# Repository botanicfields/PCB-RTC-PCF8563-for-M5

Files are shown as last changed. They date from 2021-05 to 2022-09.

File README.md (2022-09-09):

## PCB-RTC-PCF8563-for-M5
a PCB of PCF8563-RTC with Grove-I2C for M5Stack and M5Atom synchronized with NTP

# M5 用リアルタイムクロック (RTC) 基板
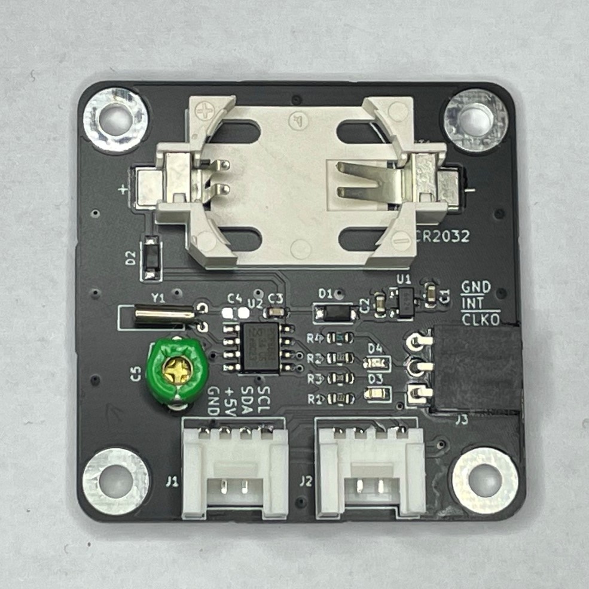
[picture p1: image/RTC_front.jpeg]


　M5 シリーズ用に作成した RTC 基板です。水晶振動子 により高精度に時刻を刻みます。バッテリ・バックアップにより本体が電源オフの状態でも時刻を維持します。

- M5 仕様の Grove コネクタ

    　M5 製品の Grove コネクタ仕様（電源 5V, 信号レベル 3.3V）に合致します。Grove コネクタが 2 個あり、I2C デバイスの数珠つなぎができます。

- M5 製品と同仕様の RTC

    　M5Core2, M5StickC/C Plus, M5CoreInk, M5Paper, M5Camera/F/X に内蔵されている BM8563 と互換の RTC(PCF8563) を搭載し、M5 用の多くのソフトウェアを利用できます。

- INT, CLKO 信号出力

    　PCF8563(BM8563) の INT 信号、CLKO 信号を、基板上のピンソケットから取り出せます。これらの信号は 3.3V に 10kΩ でプルアップしています。基板上の LED（INT: 赤、CLKO： 緑）で信号オンを確認できます。

- 時刻の精度を改善

    　基板上にトリマコンデンサを搭載し、時刻の精度を改善できます。出荷時には、以下の機器を用いて室温（15 - 25 ℃程度のどこか）にて調整済です。（※固定コンデンサ C4, トリマコンデンサ C5 はどちらか一方を実装します。トリマコンデンサを実装している場合、C4 には部品がありません。）

>> 1. 周波数カウンタ (1) を GPS 受信機 (2) の 1PPS 信号で校正
>>>> (1) 秋月電子通商「８桁周波数カウンターキット」 [AE-FCOUNT3](
https://akizukidenshi.com/catalog/g/gK-13432/)
>>>>
>>>> (2) 秋月電子通商「ＧＰＳ受信機キット～」 [AE-GYSFDMAXB](
https://akizukidenshi.com/catalog/g/gK-09991/)
>> 2. RTC 基板の CLKO から 1Hz 信号を取り出し、1PPS の代わりに入力
>> 3. 周波数カウンタの表示が所定の値に近づく様、RTC 基板上のトリマを調整

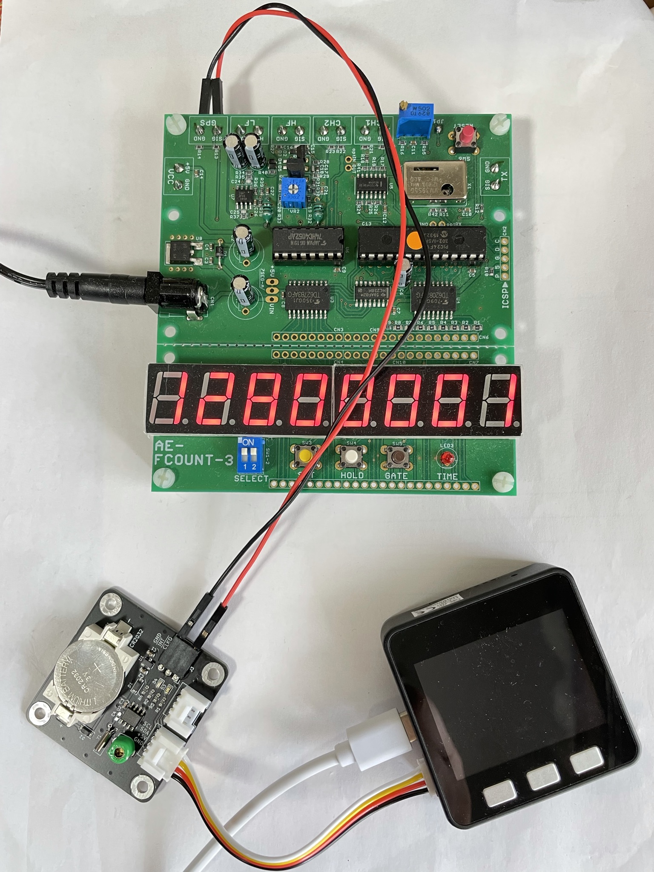
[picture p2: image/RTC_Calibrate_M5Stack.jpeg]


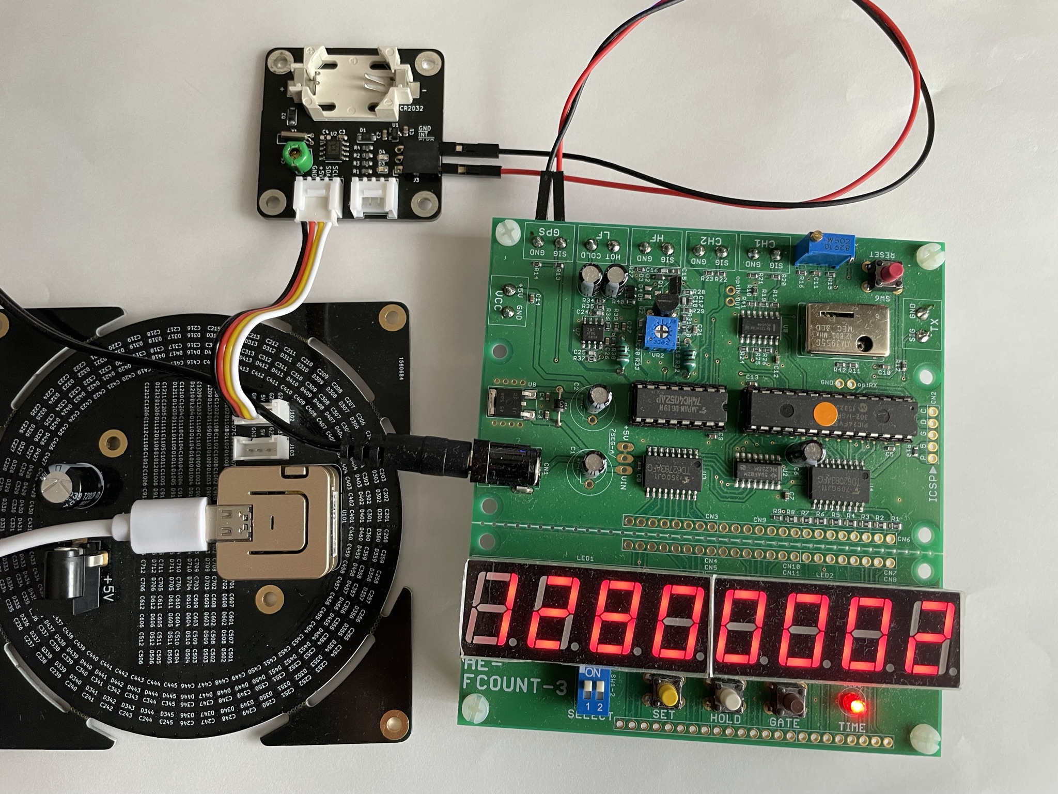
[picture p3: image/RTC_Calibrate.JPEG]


# ソフトウェア
　RTC の使用にあたっては、一般に入手可能なライブラリを利用することができます。

　他の I2C デバイスとの共存や、NTP との相互補完を想定したサンプルプログラムを作成し、BF-027 フォルダに置きました。詳細な説明は Qiita（参考を参照）にあります。これらのプログラムは M5Stack 社の [RTC ユニット](https://docs.m5stack.com/en/unit/rtc)でも使用できます。

1. BF_Pcf8563.h, BF_Pcf8563.cpp

    RTC PCF8563(BM8563) にアクセスし、時刻、アラーム、タイマー、クロック出力などの機能を使用するためのドライバです。

2. BF_Pcf8563Test.h, BF_Pcf8563Test.cpp

    上記 BF_Pcf8563.cpp の機能をテストするプログラムです。

3. BF_RtcxNtp.h, BF_RtcxNtp.cpp

    RTC と NTP を相互補完的に使用するためのプログラムです。

4. BF-027.ino

    上記プログラムの使用例です。  
- M5Stack または M5Atom で動作します。冒頭の #define で使用する方を残してコメントアウトしてください。  
- M5Atomでは RTC の接続先を GROVE コネクタか、またはピンソケットのどちらかを選べます。setup() の rtcx.Begin(Wire1) または rtcx.Begin(Wire) の使用するほうを残してコメントアウトしてください。

# 参考

(1) Qiita [「M5Atom, M5Stack Core 用の I2C リアルタイムクロック基板を作って動かす」](https://qiita.com/BotanicFields/items/dc35e12423be8f6e9b4e)

(2) Qiita [「ESP32 において NTP の時刻同期を捕まえて RTC を更新する」](https://qiita.com/BotanicFields/items/f1e28af5a63e4ccf7023)

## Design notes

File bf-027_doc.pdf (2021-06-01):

BF-027 V02

Copyright 2021 BotanicFields, Inc. 1

## M5 用リアルタイムクロック (RTC) 基板

M5 シリーズ用に作成した RTC 基板です。水晶振動子の精度で時刻を刻みます。バックアップ電池により M5 本体が電源オフの状態でも時刻を維持します。

1. 内容物（各１）
(1) プリント基板
(2) GROVE 互換ケーブル 10cm
(3) 説明書（本書）
※電池 (CR2032) は付属しません。
2. 使用方法
(1) バックアップ電池を装着すると、電源オフでも時刻を維持します
(2) GROVE コネクタ 2 個は、どちらも同じです。バス接続に利用できます
(3) GROVE コネクタは M5 シリーズの仕様に合わせ、電源は 5V, 信号 (I2C) は 3.3V です。
(4) RTC 基板上に I2C のプルアップはありません。コントローラ側などでプルアップが必要です
(5) I2C アドレスは 0x51 固定です。PCF8563/BM8563 用のソフトウェアには設定済と思います。I2C 初 期化時の SCL, SDA 設定と、M5 本体から I2C バスを取り出す GPIO 番号を合わせてください
3. ご注意
(1) 基板むき出しであり、配線に触ると誤動作します。たとえバックアップ電池を装備していても、コネクタ の抜き差し時に誤動作して時刻を喪失することもあります。
(2) トリマコンデンサは可能なかぎり調整済ですが、精度の保証はいたしません
(3) 電池 CR2032 の短絡や寿命（ 5 年）にご注意ください
(4) 本製品の誤動作やご利用上のトラブル等への補償はいたしません
4. 参考情報
(1) GitHub 「botanicfields/PCB-RTC-PCF8563-for-M5」 https://github.com/botanicfields/PCB-RTC-PCF8563-for-M5
(2) Qiita 「M5Atom, M5Stack Core 用の I2C リアルタイムクロック基板を作って動かす」 https://qiita.com/BotanicFields/items/dc35e12423be8f6e9b4e
(3) Qiita 「ESP32 において NTP の時刻同期を捕まえて RTC を更新する」 https://qiita.com/BotanicFields/items/f1e28af5a63e4ccf7023
5. 提供元
ボタニック (BotanicFields)
https://www.facebook.com/botanicfieldshttps://twitter.com/botanicfields
以上

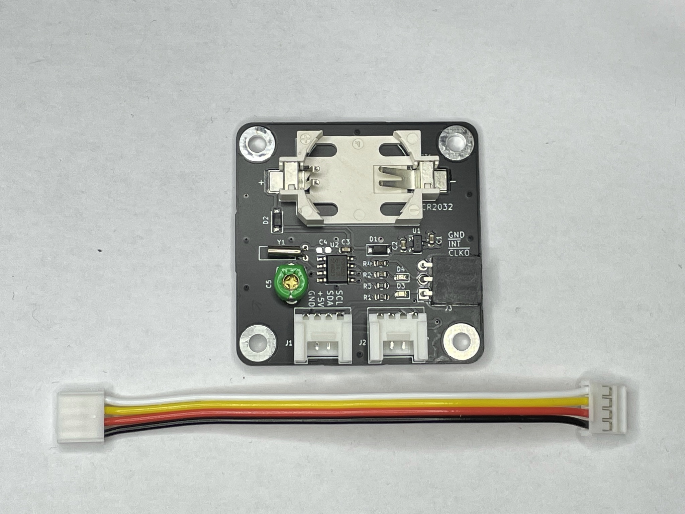
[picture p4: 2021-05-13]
image/RTC_kit.JPEG

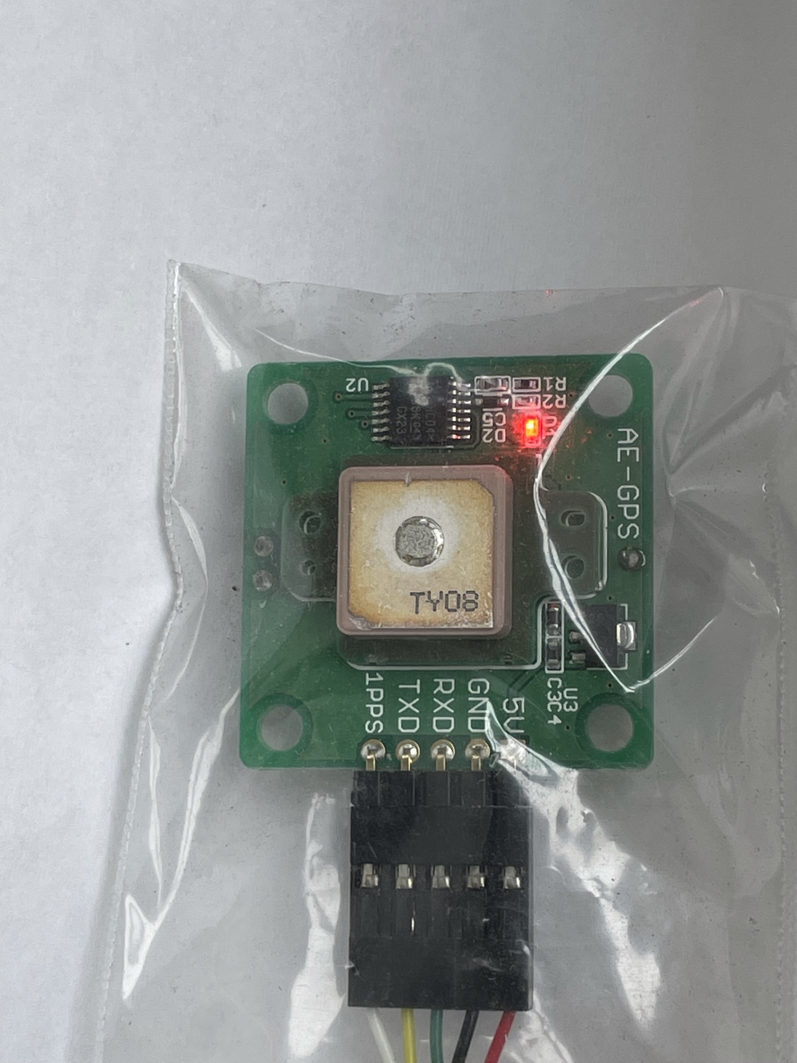
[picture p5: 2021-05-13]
image/GPS.JPEG

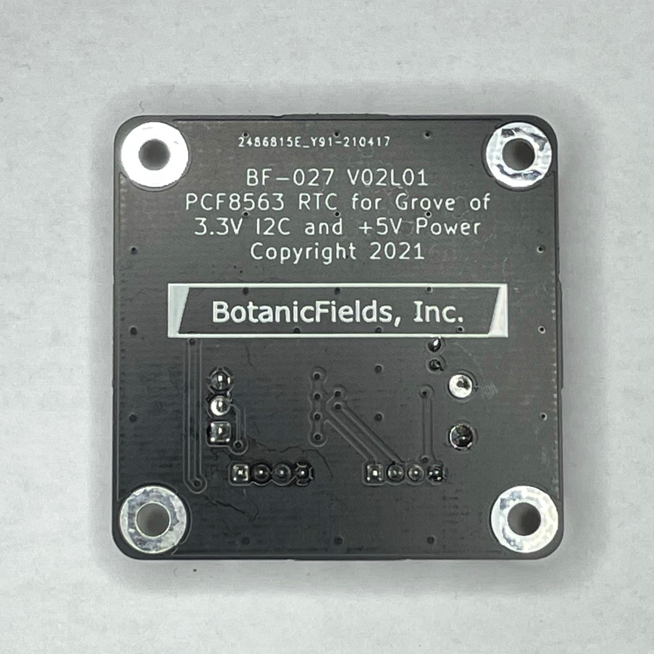
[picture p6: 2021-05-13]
image/RTC_back.jpeg

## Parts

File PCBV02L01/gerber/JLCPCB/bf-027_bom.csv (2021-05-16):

Comment | Designator | Footprint | LCSC
CR2032 | BT1 | bf:BF@QJ-BS-6 | C70377
1u | C1,C2 | Capacitor_SMD:C_0603_1608Metric | C15849
100n | C3 | Capacitor_SMD:C_0603_1608Metric | C14663
15p | C4 | Capacitor_SMD:C_0603_1608Metric | C1644
30p | C5 | bf:BF@TZ03-F
1N4148 | D1,D2 | Diode_SMD:D_SOD-123 | C81598
GREEN | D3 | LED_SMD:LED_0603_1608Metric | C72043
RED | D4 | LED_SMD:LED_0603_1608Metric | C2286
I2C | J1,J2 | opl:HW4-2.0-90D
OUT | J3 | bf:BF@PinSocket_1x03_P2.54mm_Horizontal | C225511
2.2k | R1,R2 | Resistor_SMD:R_0603_1608Metric | C4190
10k | R3,R4 | Resistor_SMD:R_0603_1608Metric | C25804
XC6206P332MR | U1 | Package_TO_SOT_SMD:SOT-23 | C5446
PCF8563T | U2 | Package_SO:SOIC-8_3.9x4.9mm_P1.27mm | C7440
32768Hz | Y1 | bf:BF@Crystal_DS26_D2.0mm_L6.0mm_Horizontal | C398714

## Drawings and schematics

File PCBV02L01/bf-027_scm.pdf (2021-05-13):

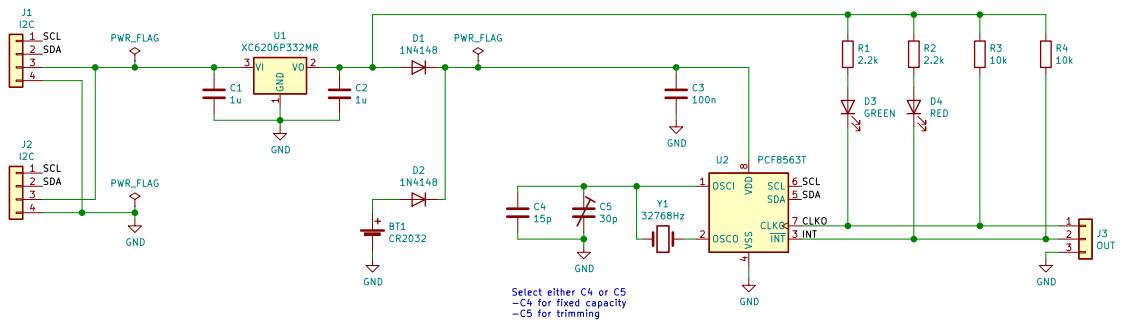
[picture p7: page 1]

File: bf-027.sch Sheet: / Copyright 2021 BotanicFields, Inc. PCF8563 RTC for Grove of 3.3V I2C 5V Power D3 GREEN GND

4 SDA 5 SCL 6 CLKO 7 VDD

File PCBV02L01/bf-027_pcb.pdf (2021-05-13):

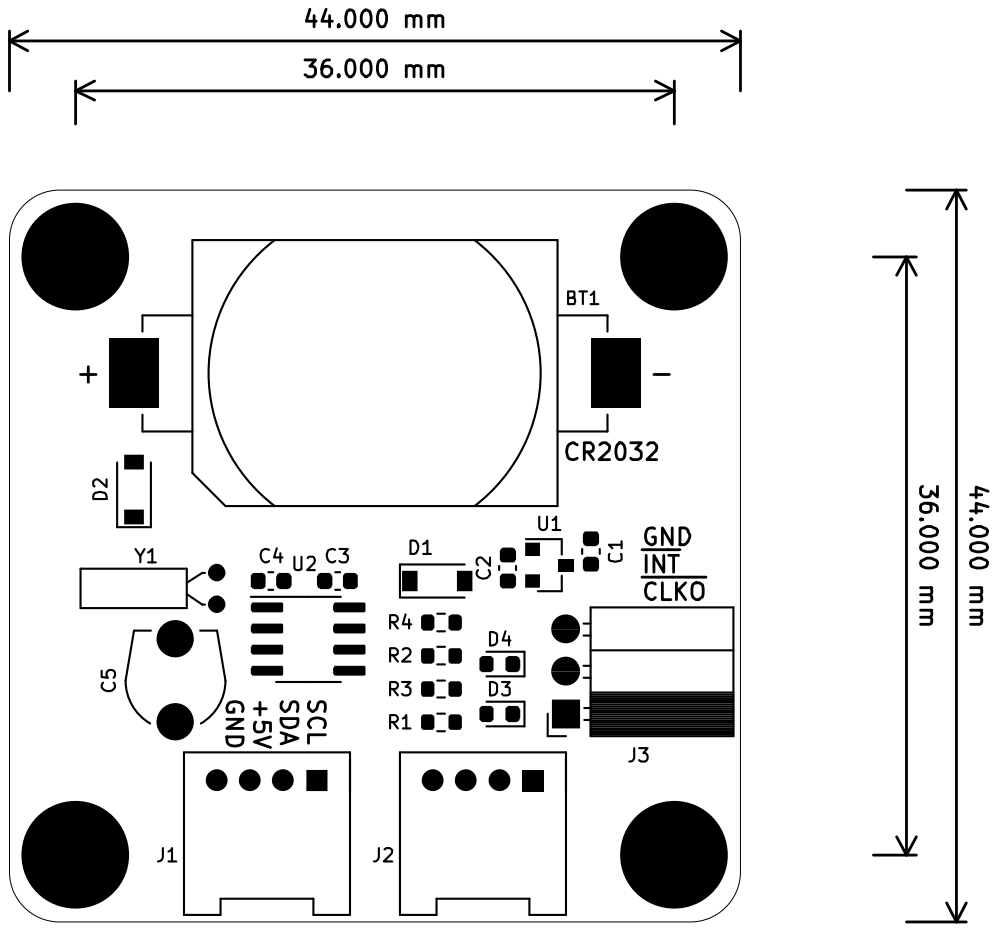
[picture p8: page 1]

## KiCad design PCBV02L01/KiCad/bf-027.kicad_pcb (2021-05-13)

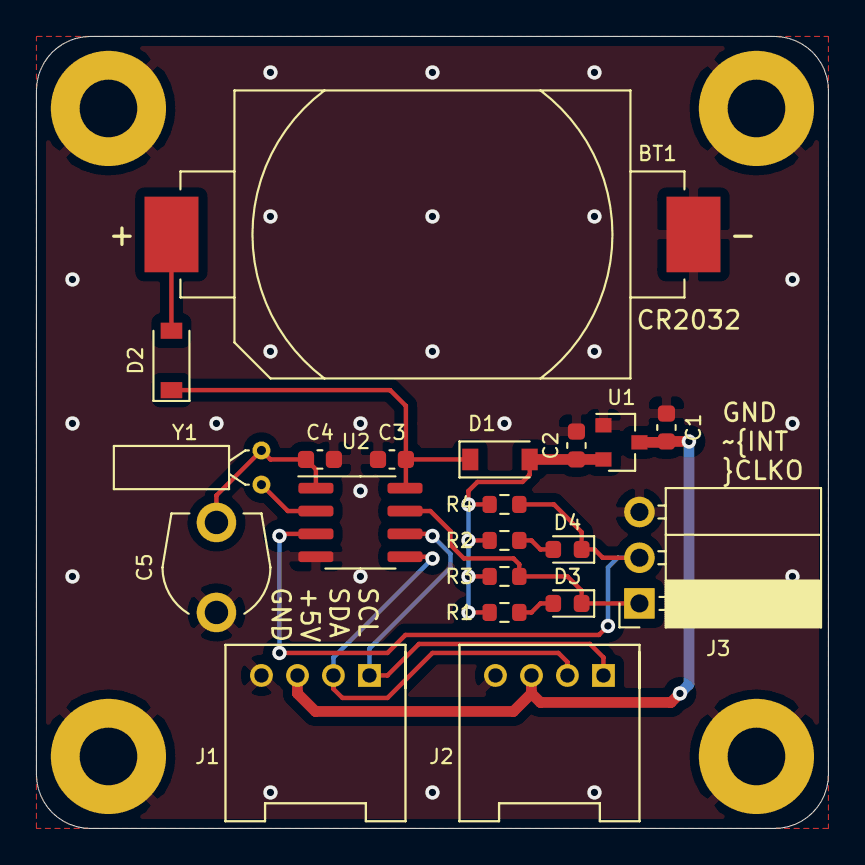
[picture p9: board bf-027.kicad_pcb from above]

Board: 2 copper layers, 44.0 x 44.0 mm, 20 parts (0 on the bottom side), 13 nets.

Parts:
BT1: CR2032; BF@QJ-BS-6
C1, C2: 1u; C_0603_1608Metric
C3: 100n; C_0603_1608Metric
C4: 15p; C_0603_1608Metric
C5: 30p; BF@TZ03-F
D1, D2: 1N4148; D_SOD-123
D3: GREEN; LED_0603_1608Metric
D4: RED; LED_0603_1608Metric
J1, J2: I2C; HW4-2.0-90D
J3: OUT; BF@PinSocket_1x03_P2.54mm_Horizontal
R1, R2: 2.2k; R_0603_1608Metric
R3, R4: 10k; R_0603_1608Metric
U1: XC6206P332MR; SOT-23
U2: PCF8563T; SOIC-8_3.9x4.9mm_P1.27mm
Y1: 32768Hz; BF@Crystal_DS26_D2.0mm_L6.0mm_Horizontal

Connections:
/CLKO: D3.1, J3.1, R3.2, U2.7
/INT: D4.1, J3.2, R4.2, U2.3
/SCL: J1.1, J2.1, U2.6
/SDA: J1.2, J2.2, U2.5
GND: BT1.2, C1.2, C2.2, C3.2, C4.2, C5.2, J1.4, J2.4, J3.3, U1.1, U2.4
unnamed: BT1.1, D2.2
unnamed: C1.1, J1.3, J2.3, U1.3
unnamed: C2.1, D1.2, R1.1, R2.1, R3.1, R4.1, U1.2
unnamed: C3.1, D1.1, D2.1, U2.8
unnamed: C4.1, C5.1, U2.1, Y1.1
unnamed: D3.2, R1.2
unnamed: D4.2, R2.2
unnamed: U2.2, Y1.2

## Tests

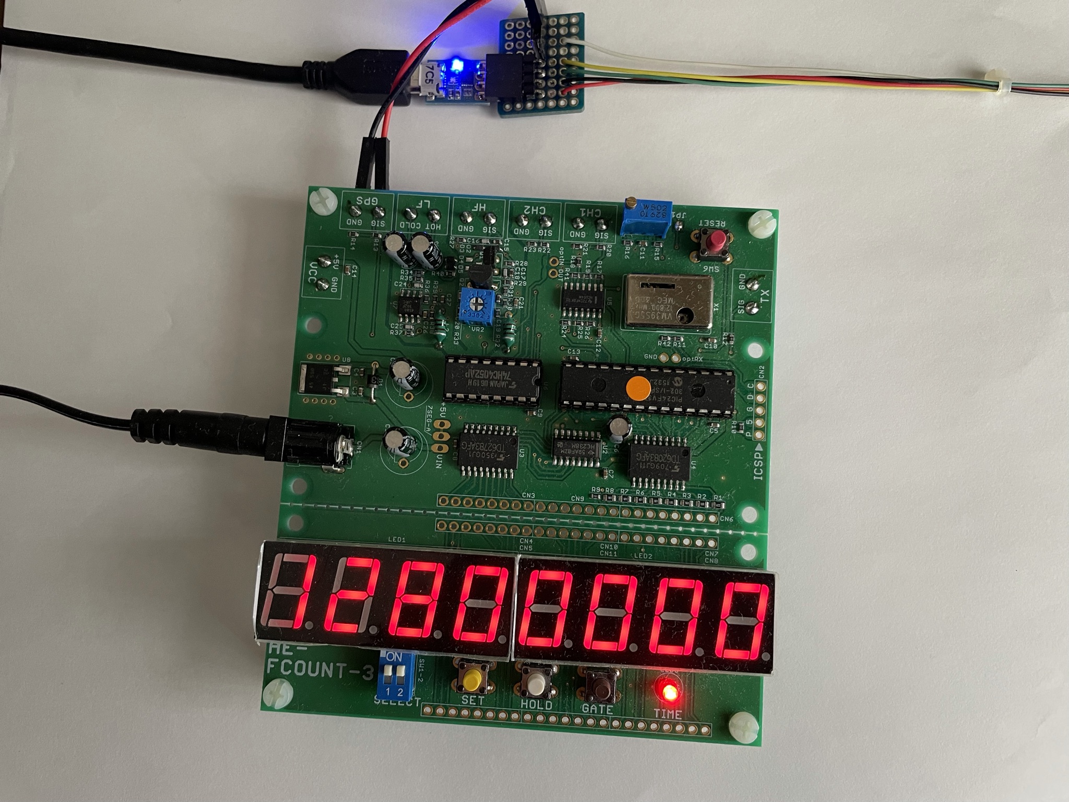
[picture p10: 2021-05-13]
image/GPS_Calibrate.JPEG

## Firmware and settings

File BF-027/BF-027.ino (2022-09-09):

// Copyright 2021 BotanicFields, Inc.
// BF-027 PCF8563 RTC for Grove I2C
// test and start example

//#define M5STACK
#define M5ATOM

#ifdef M5STACK
  #include <M5Stack.h>
#endif

#ifdef M5ATOM
  #include <M5Atom.h>
#endif

#include <WiFi.h>
#include <WiFiManager.h>
#include "BF_Pcf8563.h"
#include "BF_RtcxNtp.h"
#include "BF_Pcf8563Test.h"

//..:....1....:....2....:....3....:....4....:....5....:....6....:....7..
// for NTP
const char* time_zone  = "JST-9";
const char* ntp_server = "pool.ntp.org";
bool localtime_valid(false);

//..:....1....:....2....:....3....:....4....:....5....:....6....:....7..
// for WiFi
const int wifi_config_portal_timeout_sec(60);

wl_status_t wifi_status(WL_NO_SHIELD);

const char* wl_status_str[] = {
  "WL_IDLE_STATUS",      // 0
  "WL_NO_SSID_AVAIL",    // 1
  "WL_SCAN_COMPLETED",   // 2
  "WL_CONNECTED",        // 3
  "WL_CONNECT_FAILED",   // 4
  "WL_CONNECTION_LOST",  // 5
  "WL_DISCONNECTED",     // 6
  "WL_NO_SHIELD",        // 7 <-- 255
  "wl_status invalid",   // 8
};

const char* WlStatus(wl_status_t wl_status)
{
  if (wl_status >= 0 && wl_status <= 6) {
    return wl_status_str[wl_status];
  }
  if (wl_status == 255) {
    return wl_status_str[7];
  }
  return wl_status_str[8];
}

void WifiCheck()
{
  wl_status_t wifi_status_new = WiFi.status();
  if (wifi_status != wifi_status_new) {
    wifi_status = wifi_status_new;
    Serial.printf("[WiFi]%s\n", WlStatus(wifi_status));
  }
}

//..:....1....:....2....:....3....:....4....:....5....:....6....:....7..
// for loop control
const unsigned int loop_period_ms(100);  // 100ms
      unsigned int loop_last_ms;
const unsigned int compare_interval_ms(600000);  // 10 minutes
      unsigned int compare_last_ms;

void setup()
{
#ifdef M5STACK
  const bool lcd_enable(true);
  const bool sd_enable(true);
  const bool serial_enable(true);
  const bool i2c_enable(true);  // SCL = GPIO22, SDA = GPIO21, frequency = 100kHz;
  M5.begin(lcd_enable, sd_enable, serial_enable, i2c_enable);

  rtcx.Begin(Wire);
#endif

#ifdef M5ATOM
  const bool serial_enable(true);
  const bool i2c_enable(true);  // SCL = GPIO21, SDA = GPIO25, frequency = 100kHz;
  const bool display_enable(true);
  M5.begin(serial_enable, i2c_enable, !display_enable);

  const int      wire1_scl(32);       // GPIO32
  const int      wire1_sda(26);       // GPIO26
  const uint32_t wire1_freq(100000);  // 100kHz
  Wire1.begin(wire1_sda, wire1_scl, wire1_freq);

//  rtcx.Begin(Wire);  // connect to Pin Socket
  rtcx.Begin(Wire1);   // connect to GROVE
#endif

  SetTimeFromRtcx(time_zone);
  struct tm local_tm;
  getLocalTime(&local_tm);
  Serial.print(&local_tm, "localtime: %A, %B %d %Y %H:%M:%S\n");
  // print sample: must be < 64
  //....:....1....:....2....:....3....:....4....:....5....:....6....
  //localtime: Wednesday, September 11 2021 11:10:46

  // RTCx PCF8563: function tests
  TestControl();
  TestAlarm();
  TestClockOut();
  TestSetTimer();
  TestGetInterrupt();
  TestTimerPulse();

  // WiFi connect
  WiFiManager wm;  // blocking mode only
  wm.setConfigPortalTimeout(wifi_config_portal_timeout_sec);
  wm.autoConnect();
  WiFi.setSleep(false);  // https://macsbug.wordpress.com/2021/05/02/buttona-on-m5stack-does-not-work-properly/

  // NTP start
  NtpBegin(time_zone, ntp_server);

  // RTCx PCF8563: disable CLKO and INT
  const bool enable_clock_out(true);
  rtcx.ClockOutForTrimmer(!enable_clock_out);
  rtcx.DisableTimer();
  rtcx.DisableTimerInterrupt();

  // loop control
  loop_last_ms = millis();
  compare_last_ms = loop_last_ms;
}

void loop()
{
  M5.update();

  // WiFi status
  WifiCheck();

  // NTP sync
  RtcxUpdate();

  // compare RTCx to NTP
  unsigned int now_ms = millis();
  if (now_ms - compare_last_ms > compare_interval_ms) {
    compare_last_ms = now_ms;
    CompareRtcxTime();
  }

  // loop control
  unsigned int delay_ms(0);
  unsigned int elapse_ms = millis() - loop_last_ms;
  if (elapse_ms < loop_period_ms) {
    delay_ms = loop_period_ms - elapse_ms;
  }
  delay(delay_ms);
  loop_last_ms = millis();
//  Serial.printf("loop elapse = %dms\n", elapse_ms);  // monitor elapsed time
}

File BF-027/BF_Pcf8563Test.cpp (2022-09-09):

// Copyright 2021 BotanicFields, Inc.
// BF-027 PCF8563 RTC for Grove I2C
// test of BF_Pcf8563.h/cpp

#include <Arduino.h>
#include <sys/time.h>  // for struct TimeSpec
#include "BF_Pcf8563.h"
#include "BF_Pcf8563Test.h"

//..:....1....:....2....:....3....:....4....:....5....:....6....:....7....:....8
void TestControl()
{
  Serial.println("\n[PCF8563] test: control");
  rtcx.ReadControl();  PrintControl();  Serial.println();

  rtcx.external_clock_test_mode = true;   PrintTestControl();
  rtcx.source_clock_stoped      = true;   PrintTestControl();
  rtcx.power_on_reset_override  = false;  PrintTestControl();
  rtcx.power_on_reset_override  = true;   PrintTestControl();
  rtcx.source_clock_stoped      = false;  PrintTestControl();
  rtcx.external_clock_test_mode = false;  PrintTestControl();
}

void PrintTestControl()
{
  rtcx.WriteControl();
  rtcx.ReadControl();  PrintControl();  Serial.println();
}

//..:....1....:....2....:....3....:....4....:....5....:....6....:....7....:....8
void CompareRtcxTime()
{
  struct tm tm_glt;
  struct tm tm_rtcx;

  PrintTimeSpec();
  getLocalTime(&tm_glt);
  Serial.print(&tm_glt, "getLocalTime = %A, %B %d %Y %H:%M:%S;  ");
  rtcx.ReadTime(&tm_rtcx);
  Serial.print(&tm_rtcx, "RTCx = %A, %B %d %Y %H:%M:%S;  ");
  // print sample: must be < 64
  //....:....1....:....2....:....3....:....4....:....5....:....6....
  //getLocalTime = Wednesday, September 11 2021 11:10:46;
  //RTCx = Wednesday, September 11 2021 11:10:46;

  Serial.printf("RTCx - gLT = %d\n", (int)mktime(&tm_rtcx) - (int)mktime(&tm_glt));
}

void PrintTimeSpec()
{
  struct timespec ts;  // time spec: second, nano-second
  clock_gettime(CLOCK_REALTIME, &ts);
  Serial.printf("test: TimeSpec = %10d %09d;  ", (int)ts.tv_sec, (int)ts.tv_nsec);
}

//..:....1....:....2....:....3....:....4....:....5....:....6....:....7....:....8
struct tm tm_test;

void TestAlarm()
{
  Serial.println("\n[PCF8563] test: alarm");
  rtcx.ReadAlarm();  PrintAlarm();  Serial.println();

  //            m   h   d   w  am  ah  ad  aw        match
  TestAlarmSub(59, 23, 11, 0, -1, -1, -1,  1);  // only wday:    2021.4.11(Sun) 23:59:57 --> Mon
  TestAlarmSub(59, 23, 11, 0, -1, -1, 12, -1);  // only day:     2021.4.11(Sun) 23:59:57 --> 12
  TestAlarmSub(59,  7, 11, 0, -1,  8, -1, -1);  // only hour:    2021.4.11(Sun)  7:59:57 -->  8:xx
  TestAlarmSub(50,  9, 11, 0, 51, -1, -1, -1);  // only minute:  2021.4.11(Sun)  9:50:57 -->  x:51
  TestAlarmSub(25, 15, 11, 0, 26, 16, -1, -1);  // hour, minute: 2021.4.11(Sun) 15:25:57 --> 16:26 (no alarm)
  TestAlarmSub(25, 15, 11, 0, 26, 15, -1, -1);  // hour, minute: 2021.4.11(Sun) 15:25:57 --> 15:26
  TestAlarmSub(25, 15, 11, 0, 26, 15, 11,  0);  // all:          2021.4.11(Sun) 15:25:57 --> 15:26
}

void TestAlarmSub(int m, int h, int d, int w, int am, int ah, int ad, int aw)
{
  tm_test.tm_sec  = 57;
  tm_test.tm_min  = m;
  tm_test.tm_hour = h;
  tm_test.tm_mday = d;
  tm_test.tm_wday = w;
  tm_test.tm_mon  = 4;
  tm_test.tm_year = 121;  // 2021.04.d(w) h:m:55
  rtcx.WriteTime(&tm_test);

  rtcx.SetAlarm(am, ah, ad, aw);
  Serial.println("[PCF8563] set alarm");
  PrintTestAlarm();

  rtcx.EnableAlarmInterrupt();
  Serial.println("[PCF8563] enable alarm interrupt");

  for (int i = 0; i < 5; ++i) {
    PrintTestAlarm();
    delay(1000);
  }
  int g = rtcx.GetInterrupt();
  Serial.printf("[PCF8563] check interrupt %d\n", g);
  PrintTestAlarm();

  rtcx.DisableAlarm();
  Serial.println("[PCF8563] disable alarm");
  PrintTestAlarm();

  rtcx.DisableAlarmInterrupt();
  Serial.println("[PCF8563] disable alarm interrupt");
  PrintTestAlarm();

  Serial.println();
}

void PrintTestAlarm()
{
  rtcx.ReadAlarm();  PrintAlarm();
  rtcx.ReadTime(&tm_test);  PrintTime();
  rtcx.ReadInterrupt();  PrintInterrupt();  Serial.println();
}

//..:....1....:....2....:....3....:....4....:....5....:....6....:....7....:....8
void TestClockOut()
{
  Serial.println("\n[PCF8563] test: clock out");
  rtcx.ReadClockOut();  PrintClockOut();  Serial.println();

  rtcx.clock_out = Pcf8563::fco_32768Hz;
  rtcx.clock_out_active = true;   PrintTestClockOut();  delay(5000);
  rtcx.clock_out_active = false;  PrintTestClockOut();  delay(2000);

  rtcx.clock_out = Pcf8563::fco_1024Hz;
  rtcx.clock_out_active = true;   PrintTestClockOut();  delay(5000);
  rtcx.clock_out_active = false;  PrintTestClockOut();  delay(2000);

  rtcx.clock_out = Pcf8563::fco_32Hz;
  rtcx.clock_out_active = true;   PrintTestClockOut();  delay(5000);
  rtcx.clock_out_active = false;  PrintTestClockOut();  delay(2000);

  rtcx.clock_out = Pcf8563::fco_1Hz;
  rtcx.clock_out_active = true;   PrintTestClockOut();  delay(5000);
  rtcx.clock_out_active = false;  PrintTestClockOut();  delay(2000);
}

void PrintTestClockOut()
{
  rtcx.WriteClockOut();
  rtcx.ReadClockOut();  PrintClockOut();  Serial.println();
}

//..:....1....:....2....:....3....:....4....:....5....:....6....:....7....:....8
void TestSetTimer()
{
  Serial.println("\n[CF8563] test: set-timer");
  rtcx.ReadTimer();  PrintTimer();  Serial.println();

  const double r = 1.01;  // common ratio of geometric progression
  double t(0.0002);       // the first term
  while (t < 20000.0) {   // the last term
    double v = rtcx.SetTimer(t);
    Serial.printf("Timer set t=%11.5f v=%11.5f ", t, v);
    rtcx.ReadTimer();  PrintTimer();  Serial.println();
    t *= r;
  }
  rtcx.DisableTimer();
}

//..:....1....:....2....:....3....:....4....:....5....:....6....:....7....:....8
int test_start_ms(0);

void TestGetInterrupt()
{
  Serial.println("\n[PCF8563] test: get-interrupt");
  rtcx.ReadTimer();  PrintTimer();  Serial.println();

  for (double t = 0.2; t < 5.0; t *= 2.0) {
    Serial.println();
    test_start_ms = millis();

    double v = rtcx.SetTimer(t);
    Serial.printf("elapse=%6dms timer set t=%11.5f v=%11.5f\n", (int)millis() - test_start_ms, t, v);

    rtcx.EnableTimerInterrupt();  // enable timer interrupt
    PrintTestInterrupt("enable ");

    while (rtcx.GetInterrupt() == 0) {

      rtcx.DisableTimer();  // pause timer
      delay(1000);
      PrintTestInterrupt("pause  ");

      rtcx.EnableTimer();  // resume timer
      delay(1000);
      PrintTestInterrupt("resume ");
    }
    PrintTestInterrupt("get!   ");

    rtcx.DisableTimerInterrupt();
    PrintTestInterrupt("disable");
  }
  rtcx.DisableTimer();
}
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

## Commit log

2021-05-13 new
    new release
    [bf-027.kicad_pcb, bf-027.sch, bf-027_bom.csv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]
2021-05-16 BOM, POS for JLCPCB
    update
    [bf-027_bom.csv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]
2021-06-01 doc replaced
    button battery --> (coin) battery
2021-09-19 Arduino-ESP32 2.0.0
    <time.h>
    panic of WifiManager
2021-11-13 M5 Board Manager 2.0.0
    I2C process to update RTCx by SNTP callback, etc.
2022-02-11 Update BF-027.ino
    use unsigned int for millisec
2022-09-09 Update BF_Pcf8563Test.cpp
    Refined: serial.printf format of TimeSpec
